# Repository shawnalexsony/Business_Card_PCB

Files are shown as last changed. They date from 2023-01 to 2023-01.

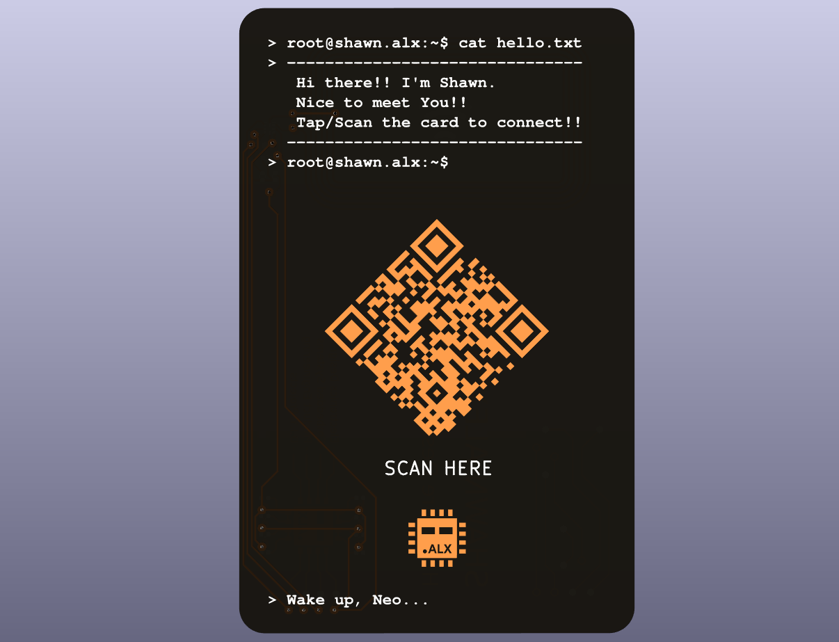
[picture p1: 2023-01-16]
PCB back view.png

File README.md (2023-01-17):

# Business Card PCB
A personal <b>Business Card</b> designed as a <b>PCB</b>. It contains an integrated <b>NFC</b> tag to share contact information wirelessly, and uses energy harvesting from NFC field to light up the LED circuitry!! 

PCB front view

The heart of this PCB is the <b>NFC</b> controller IC, the <b>NT3H1101</b> from <b>NXP Semiconductors</b>.

<b>NFC (Near Field Communication)</b> is a short-range radio technology that enables communication between devices that are held in close proximity (< 10 cm). NFC systems are based on traditional High Frequency (HF) RFID, operating at 13.56 MHz

You can store your contact information, link to your portfolio, social media, and so on, the choice is Yours!!

The form factor is maintained as a standard credit/debit card, so you can carry it around normally in your wallet.

The Schematics and PCB design is done with <b>KiCAD</b>, the Vector graphics is done with <b>Inkscape</b>.

I used the "Bitmap to Component Convertor" tool built in <b>KiCAD</b> to import my custom font text, Logo, QR code, etc. I imported them as Soldermask and Copper layer so that they'll be visible with nice HASL/ENIG finish. 
My suggestion would be to minimize the use of silkscreen, as the silkscreen print might not be of good quality for complex graphics.

The NFC tag programming was done with Tagwriter app from <b>NXP</b>. This app has multiple options to write Website Links, Phone number, Email, etc into the NTAG IC which you can customize as per your requirement.

While doing the PCB layout, please make sure you import the <b>NFC antenna</b> correctly. NXP semiconductors have a detailed guide on different types of NFC antennas and their layout template. The rest of the circuit can be done as per your design. 
<br><br>
<i>Note : Please make sure there is no Copper under the Antenna region, Best option is to define a custom keepout area so that you won't mess up the Antenna performance.</i>
<br>

PCB all layers

Feel free to use this as a reference and design your own Business Card PCBs!! Good Luck!! :)

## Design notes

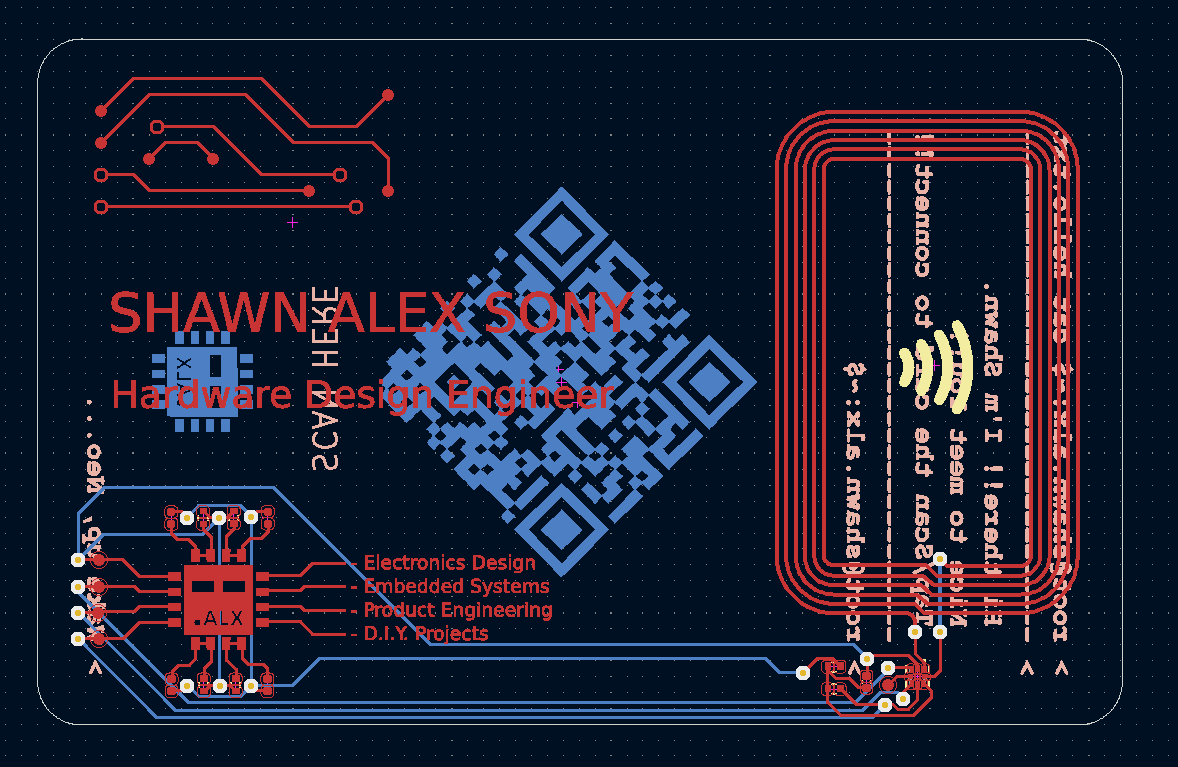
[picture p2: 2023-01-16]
PCB all layers.png

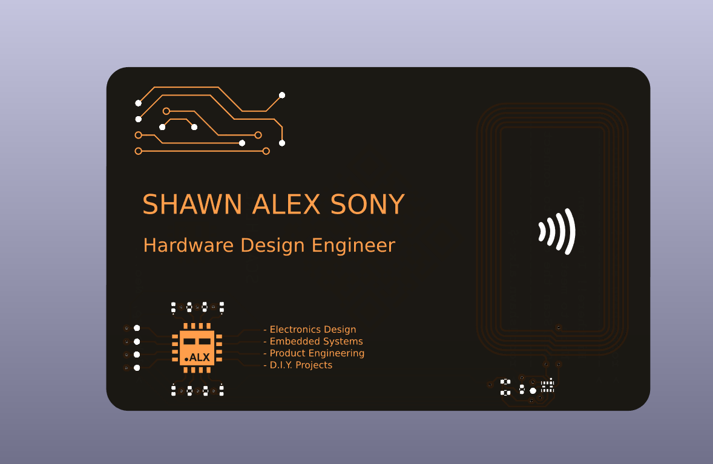
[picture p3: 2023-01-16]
PCB front view.png

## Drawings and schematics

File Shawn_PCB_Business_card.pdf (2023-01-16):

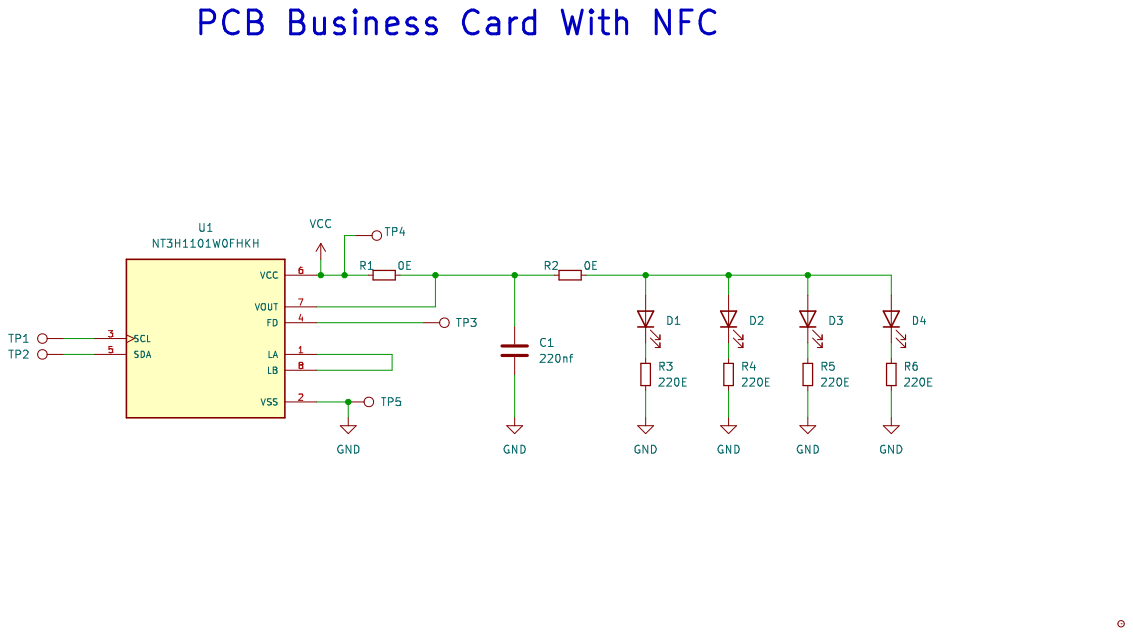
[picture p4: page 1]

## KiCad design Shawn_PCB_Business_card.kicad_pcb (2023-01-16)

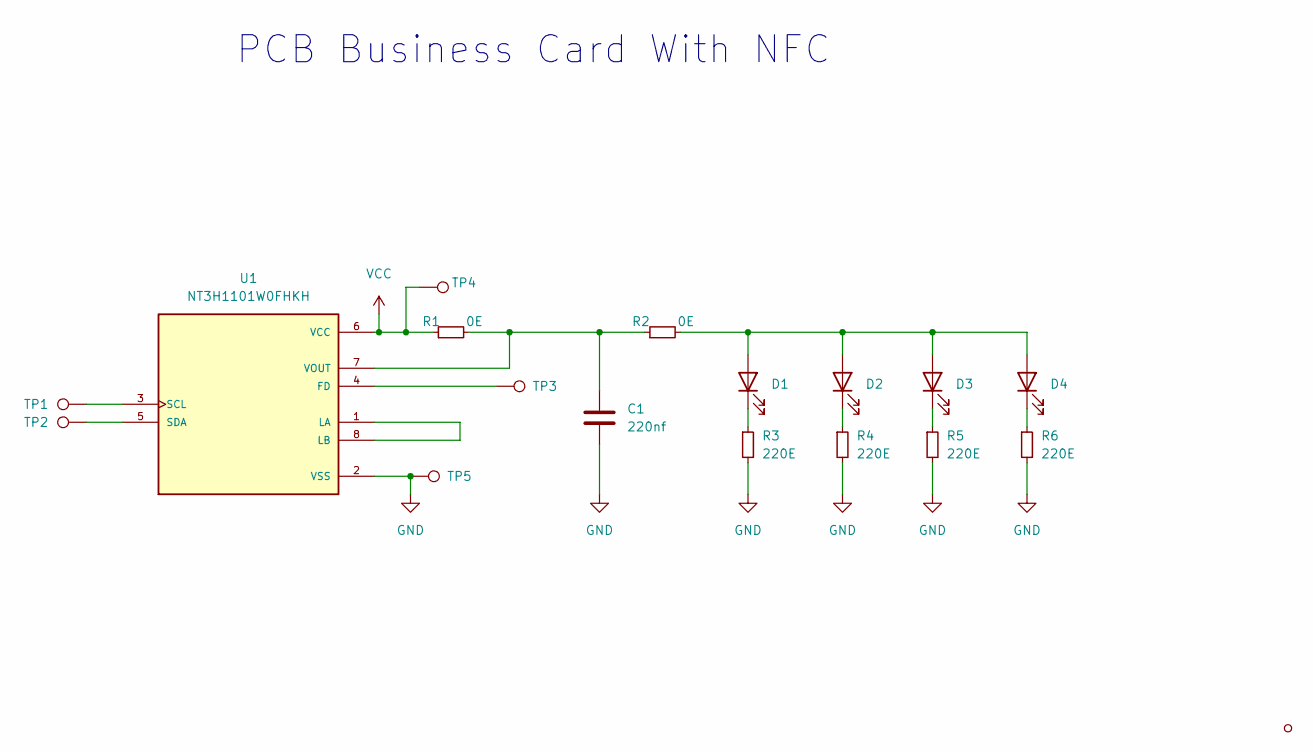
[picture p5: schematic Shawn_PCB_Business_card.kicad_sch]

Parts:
C1: 220nf; C_0402_1005Metric
D1, D2, D3, D4: LED; LED_0402_1005Metric
R1, R2: 0E; R_0402_1005Metric
R3, R4, R5, R6: 220E; R_0402_1005Metric
TP1, TP2, TP3, TP4, TP5: TestPoint; TestPoint_Pad_D1.0mm
TP6: TestPoint_Small
U1: NT3H1101W0FHKH; IC_NT3H1101W0FHKH; PARTREV 3.3

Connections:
GND: C1.2, R3.2, R4.2, R5.2, R6.2, TP5.1, U1.2 (VSS)
unnamed: C1.1, R1.2, R2.1, U1.7 (VOUT)
unnamed: D1.1 (K), R3.1
unnamed: D1.2 (A), D2.2 (A), D3.2 (A), D4.2 (A), R2.2
unnamed: D2.1 (K), R4.1
unnamed: D3.1 (K), R5.1
unnamed: D4.1 (K), R6.1
unnamed: TP1.1, U1.3 (SCL)
unnamed: TP2.1, U1.5 (SDA)
unnamed: TP3.1, U1.4 (FD)
unnamed: U1.1 (LA), U1.8 (LB)
VCC: R1.1, TP4.1, U1.6 (VCC)

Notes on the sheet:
PCB Business Card With NFC

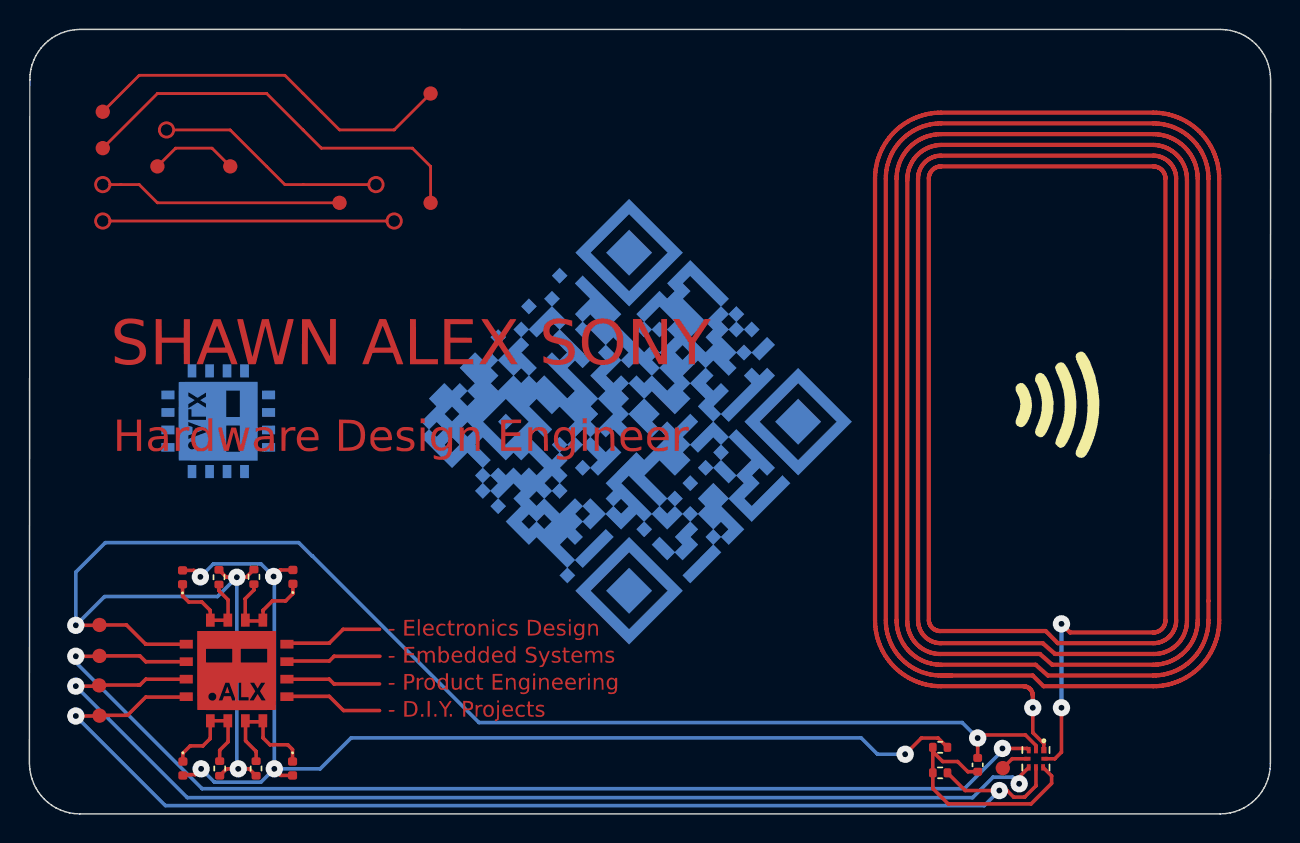
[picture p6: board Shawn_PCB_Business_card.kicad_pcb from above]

Board: 2 copper layers, 86.6 x 54.7 mm, 17 parts (0 on the bottom side), 12 nets.

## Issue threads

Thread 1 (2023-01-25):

License Missing

swalahamani, 2023-01-25:
Hi @shawnalexsony 👋

This is really amazing work 🎉 Thanks for publishing it 🙏

Could you please add a license?

shawnalexsony, 2023-01-25:
Hi @swalahamani

Thanks for the heads-up,

I've added <b>GNU General Public License v3.0</b> for this project.

Regards,
Shawn

swalahamani, 2023-01-27:
Thanks @shawnalexsony

Closed 2023-01-25.

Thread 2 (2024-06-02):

Which hardware is being used for this pcb?

ZhengLinLei, 2024-06-02:

ZhengLinLei, 2024-06-03:
I searched all NT3H1101 components, but any with 9 pads

shawnalexsony, 2024-06-10:
Hi,

I have used the part : **NT3H1101W0FHKH** from NXP semiconductors.
I ordered from JLC PCB. Please check with them.

Also, it seems some of the production build has 9 pads IC, but 9th pad is an NC pin. Datasheet shows only 8 pins, so you can use the 8 pin version since footprint also has 8 pads only.

ZhengLinLei, 2024-06-10:
Ok, thanks!

Closed 2024-06-10.
